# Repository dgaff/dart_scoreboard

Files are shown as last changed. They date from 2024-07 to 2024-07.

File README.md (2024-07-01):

# Electronic Dart Scoreboard for Cricket

## Introduction

Do you like throwing darts? Do you find the pesky chalk or dry erase scoreboards too cumbersome? Well, here's the solution.

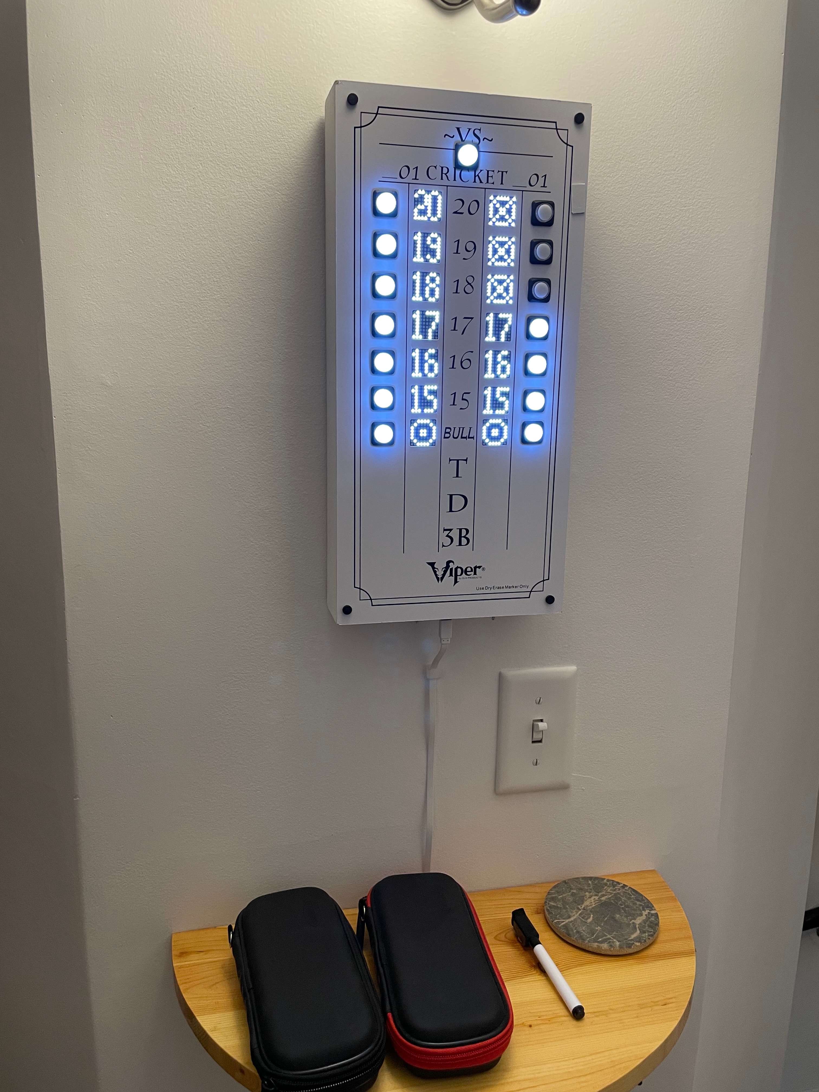
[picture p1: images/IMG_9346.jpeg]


So many lights! So many buttons!

I don't remember what possessed me to take up this project. I think I saw those 8x8 LED matrix displays on AdaFruit and wondered to myself, "Hmmm...I wonder what I could make with those?!" Anyway, this project had a ton of wiring, and because it was so tedious, I think I started and stopped it multiple times over the course of a year. It clearly needed to be a properly designed circuit board rather than a big jumble of wiring harnesses. Had I not started with the dry erase scoreboard as the base template, perhaps my brain would have led me in an easier direction. Nevertheless, it turned out really cool.

So how's it work? Just press the lighted button next to each number and the display will go through single (one slash), double (two slashes), and triple (circle) scoring. When you clear a particular number, that number's button LED will turn off. When one player clears all of the numbers, the reset button does a little animation. And there's a fun startup sequence when you power up or reset the game. I mean, if I'm going to use so many fancy chips, I might as well do something fun, right? Here's a video.

https://github.com/dgaff/dart_scoreboard/assets/1971008/4cacc433-6791-4b03-ad2a-5dbcd5b7c47d

## Parts List

This project was built with a lot of overkill components, and the total price tag was over $400 in parts. At mass production pricing, this might get under $100 in BOM cost, but it would still be pricey.

* [Dart dry erase scoreboard](https://www.amazon.com/gp/product/B004959HHO) - $15
* 14 [LED 8x8 matrix displays](https://www.adafruit.com/product/1079) - $105
* 15 [LED-lit momentary SPST pushbutton switches](https://www.adafruit.com/product/1479) - $30
* 2 [Adafruit Itsy-Bitsy M4](https://www.adafruit.com/product/3800) boards - $30
* 14 [Adafruit MAX 7219 matrix LED controllers](https://www.adafruit.com/product/453) - $182
* 2 [Adafruit TLC 59711 RGB controller](https://www.adafruit.com/product/1455) - $15
* 2 [protoboards](https://www.amazon.com/gp/product/B091PZQ4W7) 7cm x 9cm - $2
* 7 [mini protoboards](https://www.amazon.com/gp/product/B081MSKJJX) (cut in half to make 14) - $10
* 1 SPST toggle switch
* 1 DPDT toggle switch
* 1 [micro USB panel mount jack](https://www.amazon.com/gp/product/B082HZKVP1) - $13
* 1/4" 2' x 4' MDF sheet - $15
* Misc fasteners
* Lots of connector wire, some resistors, and 2 usb-micro pigtails

## Overview

The scoreboard is divided into two halves, with each half controlled by its own separate circuit. Each circuit contains an [Itsy-Bitsy M4](https://www.adafruit.com/product/3800) microprocessor, 7 [8x8 LED boards](https://www.adafruit.com/product/1079), 7 [MAX7219](https://www.adafruit.com/product/453) LED controllers, 7 [lighted push buttons](https://www.adafruit.com/product/1479), and a [TLC59711](https://www.adafruit.com/product/1455) LED controller.

Each scoring number on the scoreboard has its own 8x8 LED display controlled by a MAX7219 and a lighted pushbutton. The 7 LEDs in the push buttons are lit using the TLC59711 controller rather than directly from the microprocessor. This reduces current consumption and allows for dimming effects on the push buttons. I could have added a couple of chips to keep this to a single processor design, but I didn't. As it is, I use most of the IO pins on the Itsy-Bitsy M4.

There's also a reset button in the center that resets the game. This button triggers a reset on both processor boards. However, only the right processor board controls the reset button's LED, which has an animation effect when someone wins. So, the two separate processor boards have TTL serial between them. This is just used by the left processor board to tell the right processor board if the left side won. This will allow the right board to start the reset button animation. The code is written so that the exact same code runs on each board, though.

## Pin Mappings and Partial Schematic

Here are the pin mappings for each of the two Itsy-Bitsy M4 processors. The two processors share power and ground from a single external USB jack on the housing. The only other interconnect between the two processors is the TX and RX lines between them and a shared game reset trigger input on A5.

* SCK, MOSI = SPI bus
* D0, D1, D2, D3, D4, D5, D7 = chip select for MAX controllers (for 8x8 matrices)
* D9, D10, D11, D12, D13, A2, A3 = button inputs
* R0, G0, B0, R1, G1, B1, R2 = game button LED outputs
* G2 = reset button LED output
* A5 = game reset input
* A0, A1 = TX and RX for processor board interconnect

MAX7219 Rset = 20 k&Omega;. I did not change the built-in current limiting resistor on the 59711.

Here's a partial schematic that shows the wiring for one of the 8x8 matrices and its corresponding push button. The 8x8 MAX driver, 8x8 display, and LED pushbutton parts of the circuit are repeated another 6 times. I've labeled the other pins to indicate this. The TX and RX pins are connected to the other processor board (TX->RX and RX->TX of course).

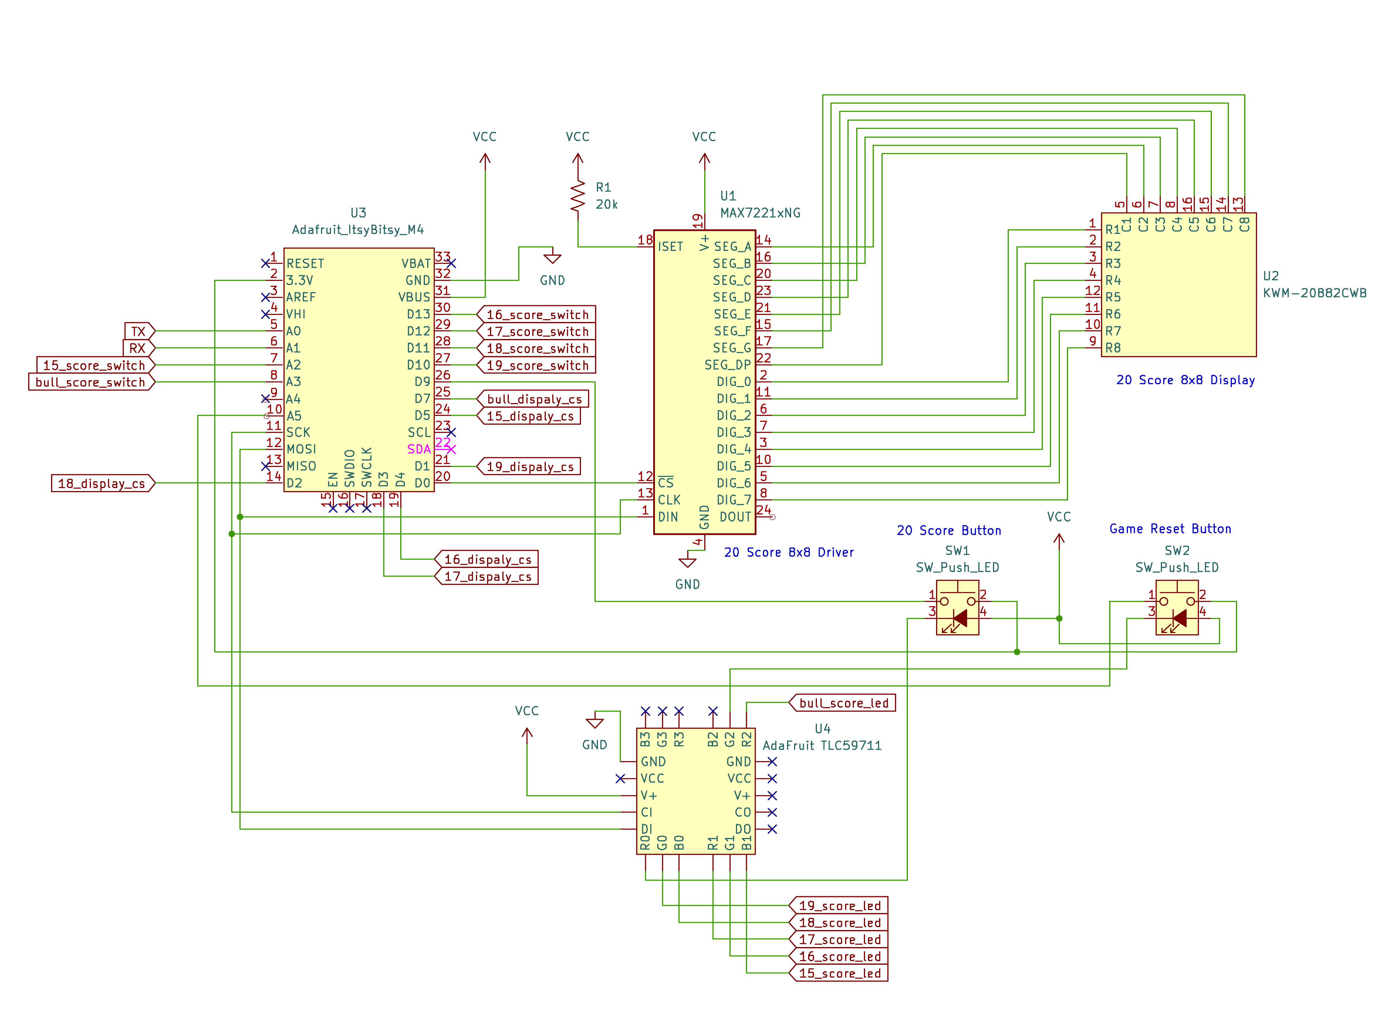
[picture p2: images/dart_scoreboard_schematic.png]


## Prototyping

Before I got too deep into this project, I did some breadboard prototyping to learn how to drive the displays. The MAX7219 controller can be driven by SPI, and each MAX needs a CS line. I had to install the display boards in a certain orientation to get the PCB boards to fit, but the CircuitPython libraries support rotation of the images.

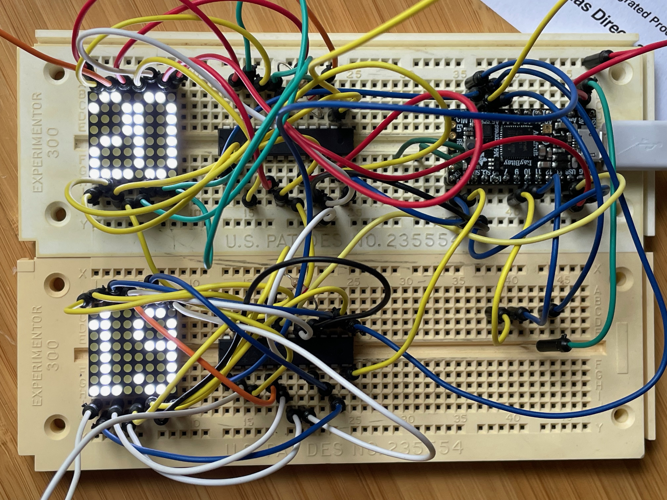
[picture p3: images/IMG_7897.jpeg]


I used the same SPI bus for both the 59711 button LED controller and the MAX7219 8x8 display controllers, as you can see on the schematic above. The 59711 doesn't have a CS like each of the MAX7219's do. But looking at the datasheets and running some tests on the logic analyzer, I decided it wasn't possible to send a bit stream to the MAX7219 controller that would mimic the 59711 bit stream (0x25 write command + 218 bits of data). So I just wired the MOSI and CLK lines to all of the MAX7219 and 59711 controllers.

## Build Steps

### Cutting out the dry erase board

I started with a [dry erase scoreboard](https://www.amazon.com/gp/product/B001E5IC78) from Amazon. I had one of these on the wall next to our dart board already. I found a [square leather punch](https://www.amazon.com/gp/product/B08PB85NFC) to make the square holes in the board for the 8x8 displays. So I made a template in CAD for each display and each push button. Important note: the spacing between each number on this cheap dry erase board is not consistent. This would have made using a single circuit board underneath more challenging. I didn't notice this until I was doing the template in CAD. Second note: at least for me, when I print from CAD (I use Rhino) to a PDF, the scaling is very slightly off when I print the PDF on my LaserJet printer. I'm not sure if this in my printer or if the PDF is off. Regardless, *measure the printout with digital calipers, and adjust the scale factor on the PDF when you print it out.* As the saying goes "measure twice, cut once."

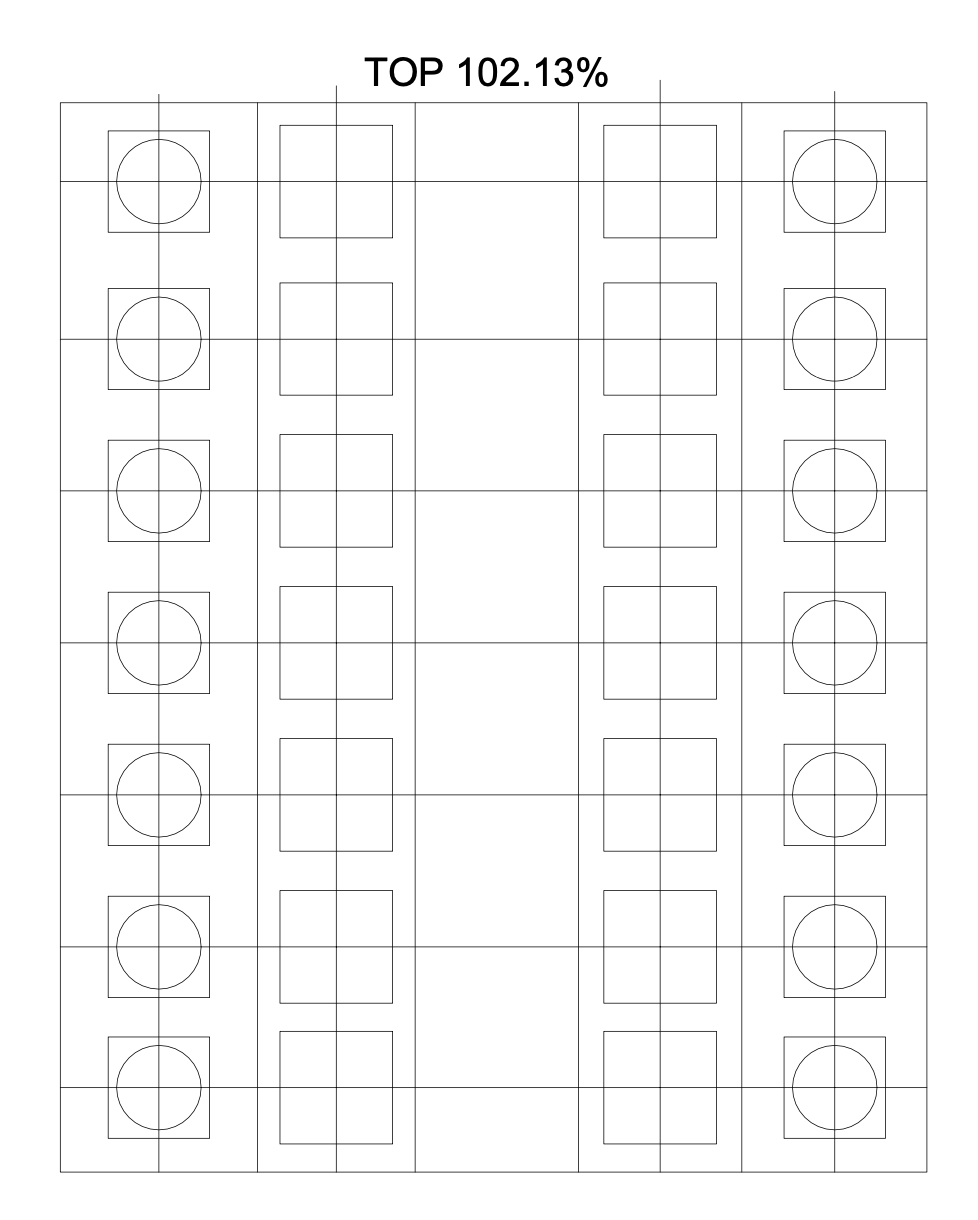
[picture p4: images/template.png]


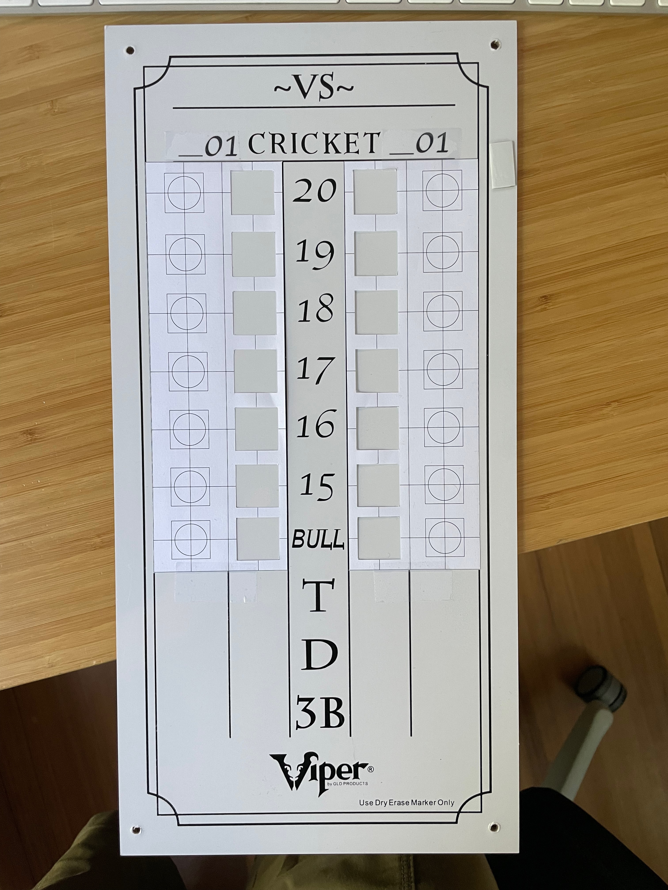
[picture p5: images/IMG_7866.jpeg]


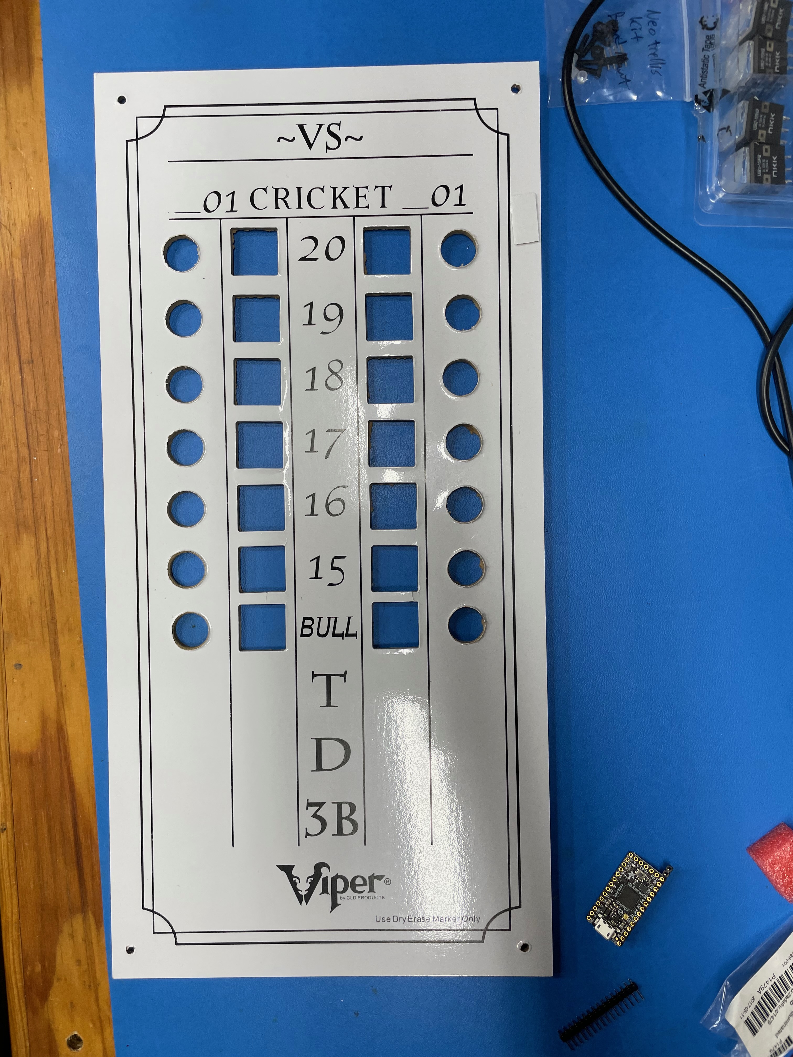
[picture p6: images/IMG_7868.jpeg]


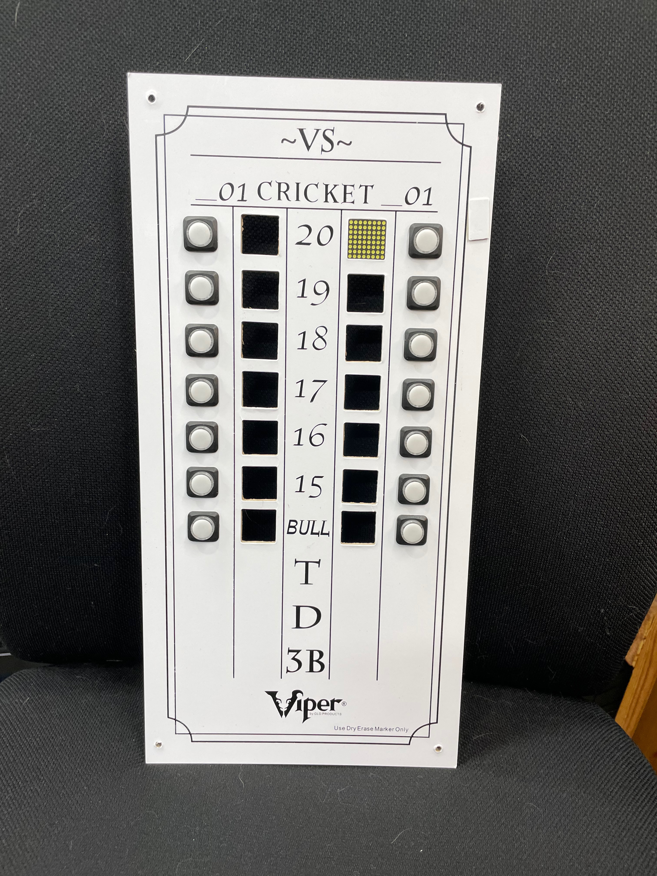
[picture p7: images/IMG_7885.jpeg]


Use the punch carefully! It took some work to cleanly cut each square. The holes for the push buttons were drilled out with a spade bit. I epoxied each display to keep them in place.



### Circuit Boards

Once again, I regret not taking the time to design a circuit board. There are enough components and wiring required that a single, large PCB would have made the job much easier. Certainly a mass-produced board would have one giant PCB for all controllers, displays, and buttons. Also, these DIP packages are large. I assume the SMC versions are quite a bit smaller and would be better suited for a PCB. Note that the MAX7219 requires a current limiting resistor (Rset). I used 20 kΩ. You can see them on the board as well.

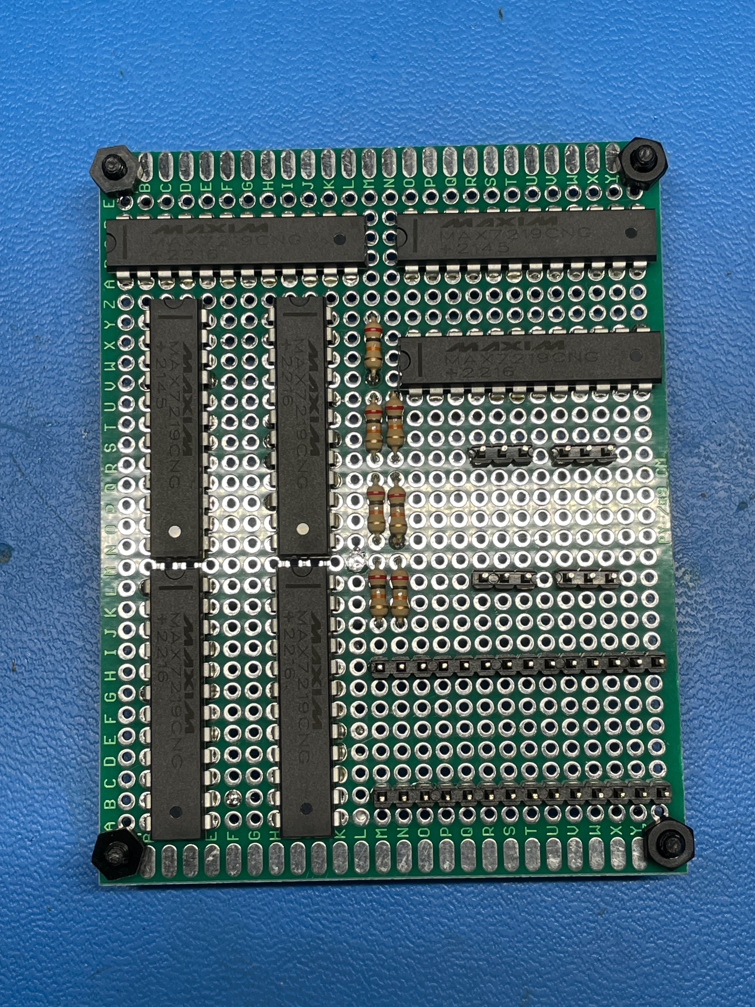
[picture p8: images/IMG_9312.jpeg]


On the top side of the board, I wired: power, ground, chip select, SCK (SPI clock), and MOSI (data).

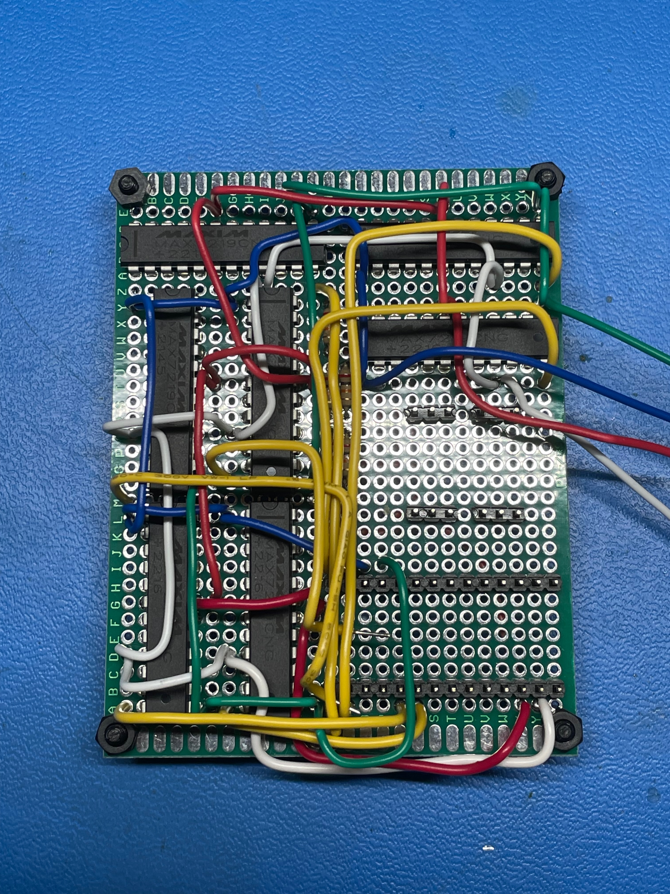
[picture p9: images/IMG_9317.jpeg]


I soldered the M4 in place at a later stage in the process, because it was easier to wire up all of the IO lines without the M4 daughter board in place. I also soldered up the 59711 controller later in the process for the same reason. The push button LED lines are much easier to solder in when the daughter board is out of the way. But this is what is looks like with the daughter boards in place. NOTE: I used solid copper wire for the top board in order to keep everything in place and mostly out of the way for the time when I would wire up the displays.

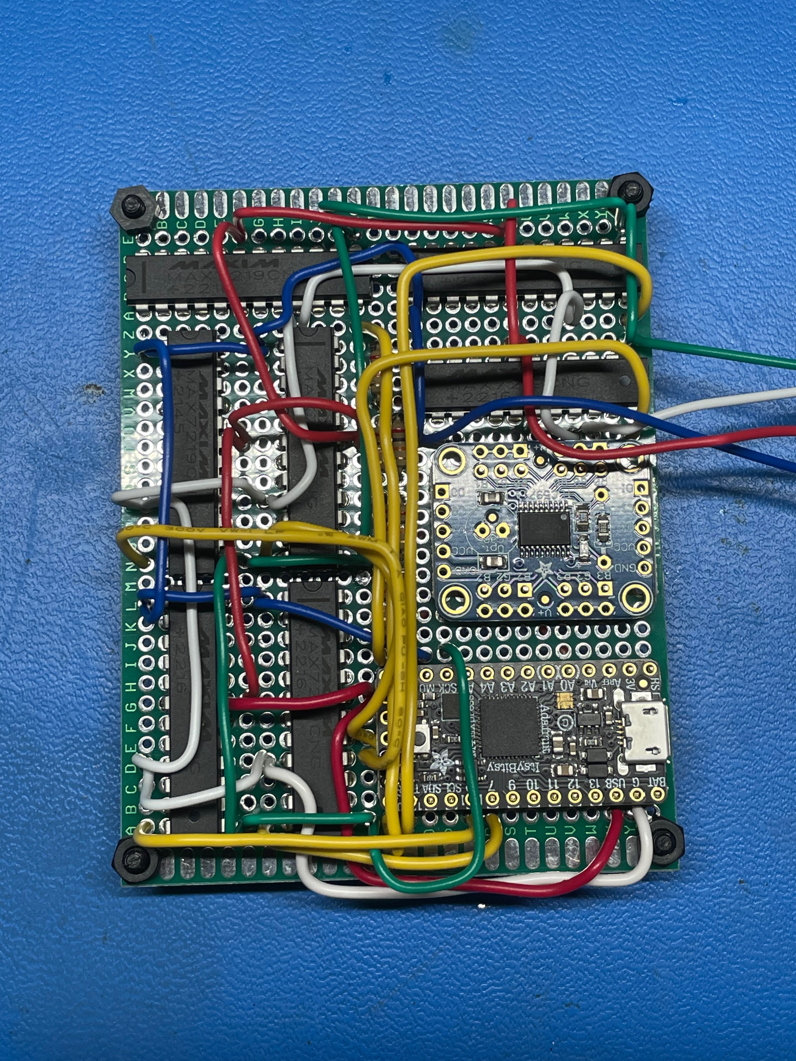
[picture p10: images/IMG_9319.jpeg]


I used the bottom of the board to wire up Rset for each MAX chip. I used stranded copper connecting wiring for this. Looking back, perhaps I could have used a single Rset for all of the MAX chips. I should have tested that out.

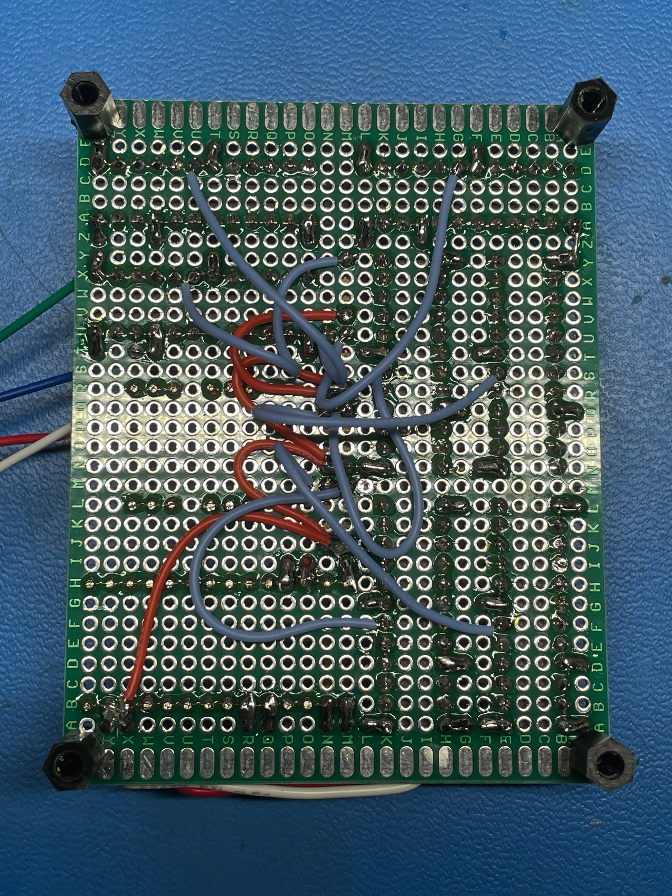
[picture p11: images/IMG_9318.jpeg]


Wiring up each 8x8 display was a real pain in the ass. First, I cut some small circuit boards in half to get them to fit next to each other on the back side of the dry erase scoreboard (given how close the 8x8 matrices were together). I had hoped I could use a single board to straddle multiple displays, but given the inconsistent font space on the dry erase scoreboard, I had to do one board for each display. (Did I mention that I started and stopped this project multiple times over the course of a year?) Then I made wiring harnesses for each display.

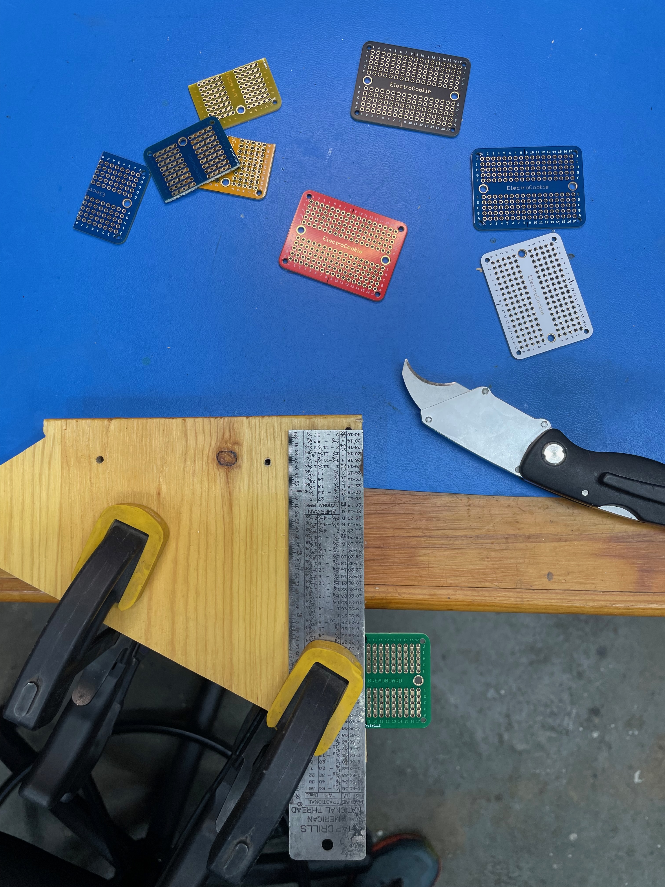
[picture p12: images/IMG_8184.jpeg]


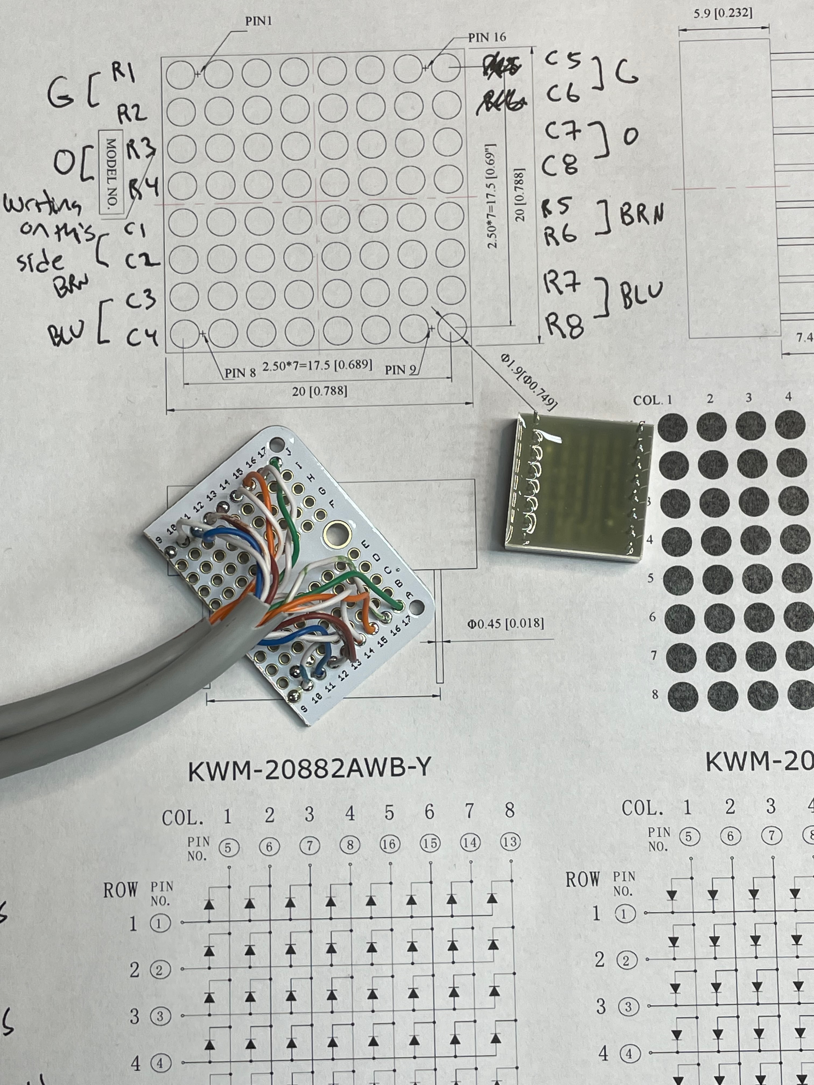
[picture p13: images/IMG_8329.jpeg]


Lastly, I made a bed-of-nails test board to check each wiring harness after it was soldered into it's corresponding MAC controller. Why? Because errors, that's why. I made a lot of wiring mistakes doing this very monotonous wiring task. This tester helped me catch those errors.

Also, there's another important reason. **The 8x8 LED datasheet warns not to use too much heat when soldering the displays and to not resolder them.** They say that you will damage the display if you use too much heat or solder for too long. So, I was worried that there was no room for error on the daughter boards, and given that these displays are epoxied in, I didn't want to have to rip one out.

That said, this bed-of-nails setup didn't work that great. The pogo pins didn't make very good electrical contact with the 8x8 daughter board. It was good enough to generally verify that I had wired up the daughter board correctly, but it wasn't perfect. Perhaps I needed some pogo pins with a sharper point. I'm not sure.



### Even more soldering...

As you can see from the picture, there was a ton of wiring and soldering to connect the display daughter board to the MAX controller chips.



And then there was soldering the 8x8 matrix daughter boards to the displays, which was stressful as I mentioned above because of the reduced temperature and limited solder time duration that the datasheet warned about.

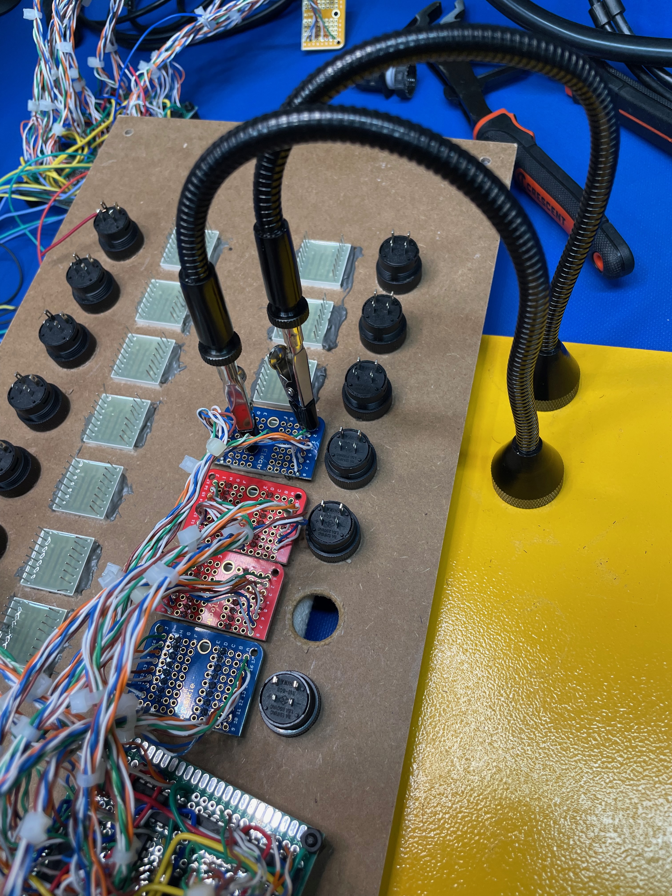
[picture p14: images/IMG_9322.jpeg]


Look at this monstrosity when everything is wired up on one side! It looks like the inside of an old school pinball machine.

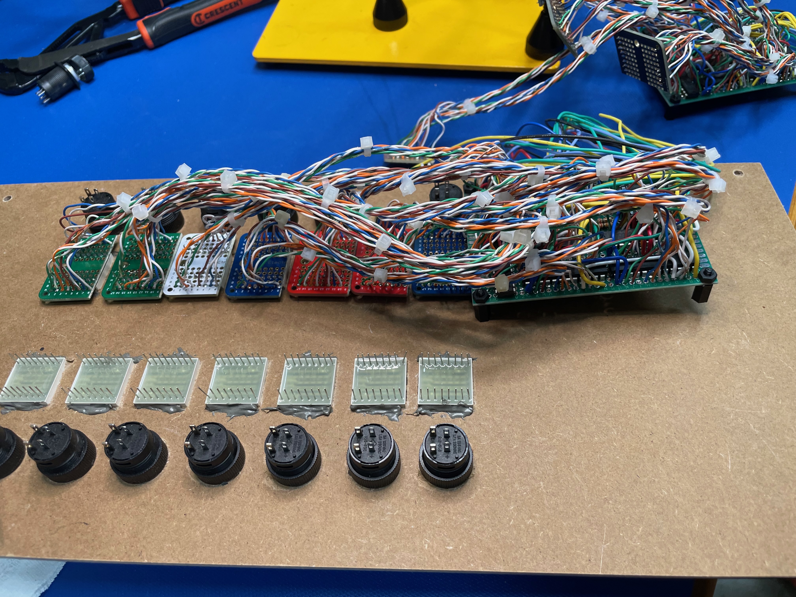
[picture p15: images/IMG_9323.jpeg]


As noted, to mass produce this, I would build one large circuit board that held the displays, push buttons, and remaining circuitry. I would also use discrete LEDs for the 8x8 matrix instead of the Luckylight modules from Adafruit. They are quite pricey. The MAX controller chips are expensive too, but I suspect the price drops quite a bit in large quantities.

### Building the housing

I bought some 1/4 inch thick MDF to build the housing for the scoreboard. Here's the frame of the box getting glued together. 1/4 MDF is a little small for nails.

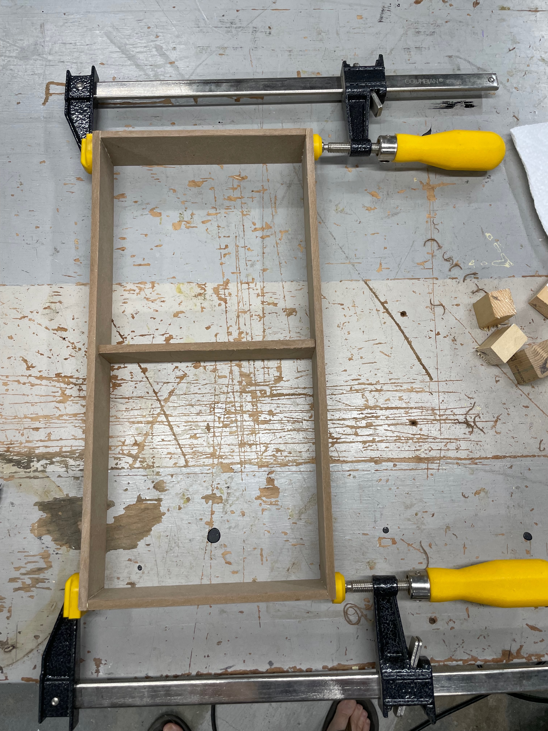
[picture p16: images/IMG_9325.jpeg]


And here's the frame getting glued to the score board.

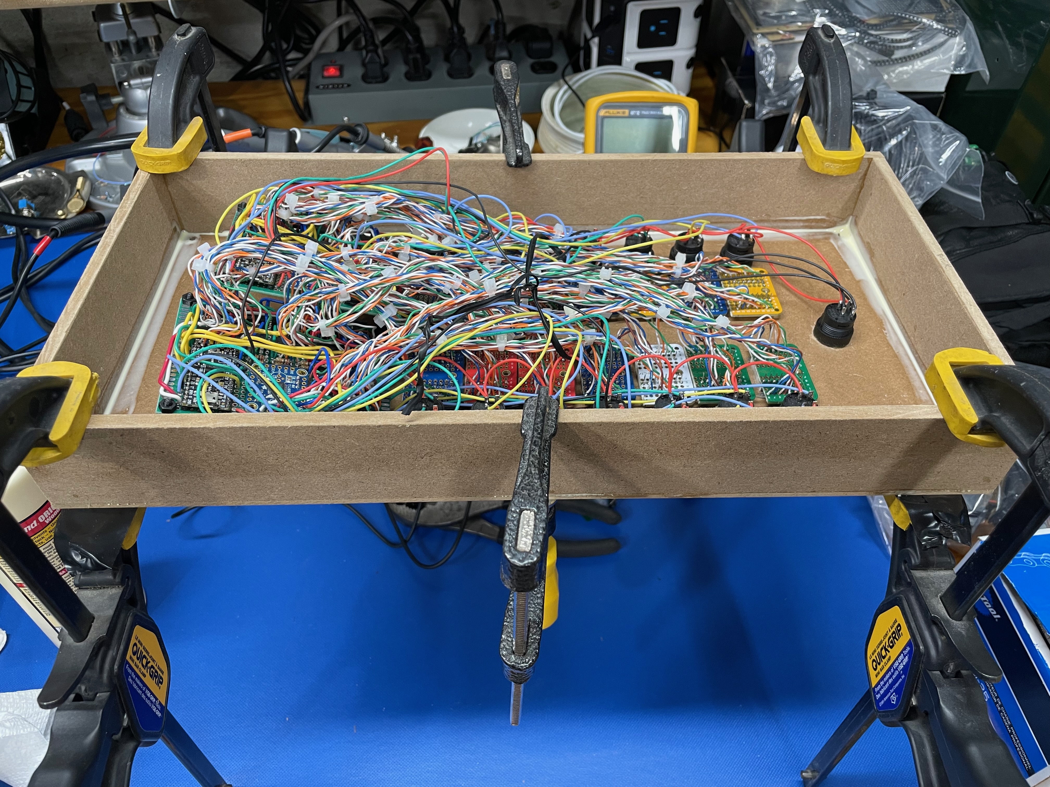
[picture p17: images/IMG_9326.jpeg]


Here's what it looked like before I added some structural components.

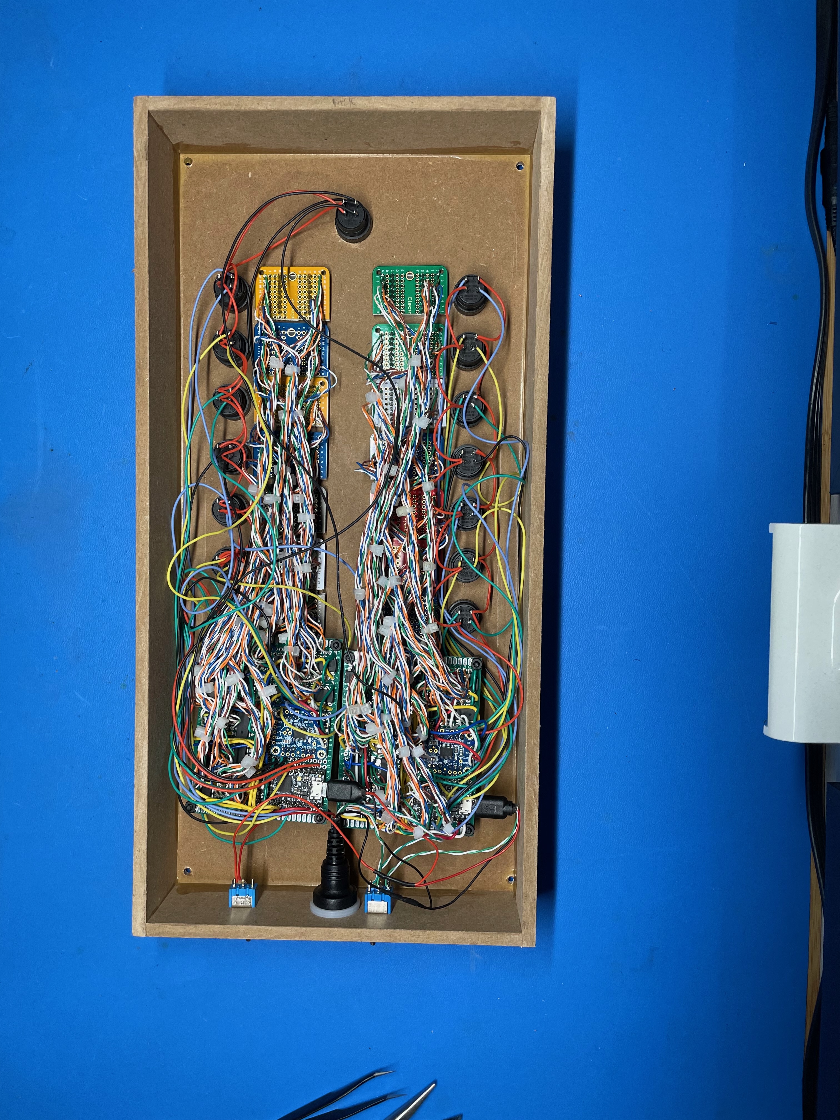
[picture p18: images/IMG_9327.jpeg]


You can see on the bottom that there are two switches and a USB jack. 

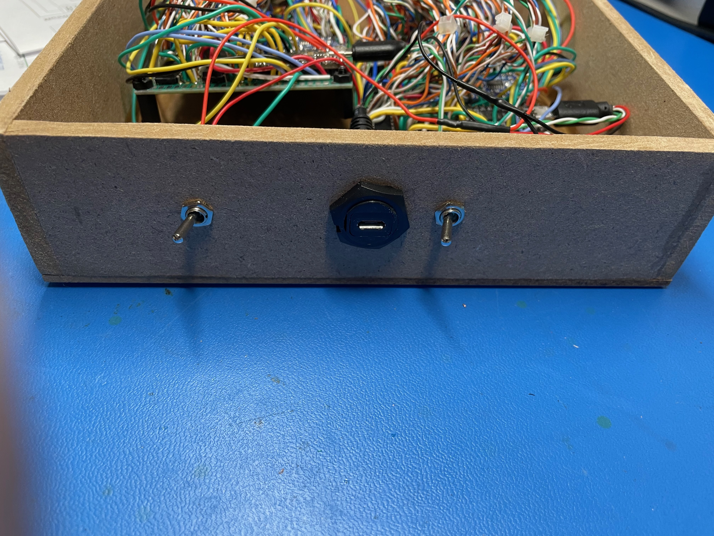
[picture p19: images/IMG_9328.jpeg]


The left switch in the picture is the power switch. Power from the single USB jack is shared between the two processor board. The right switch toggles the USB TX/RX lines between the left and right boards. This is used for programming. So when the USB is connected in the laptop, the Circuit Python drive for the selected board will shop up in Finder. This is incredibly convenient for testing out new code. You can see the wiring here.

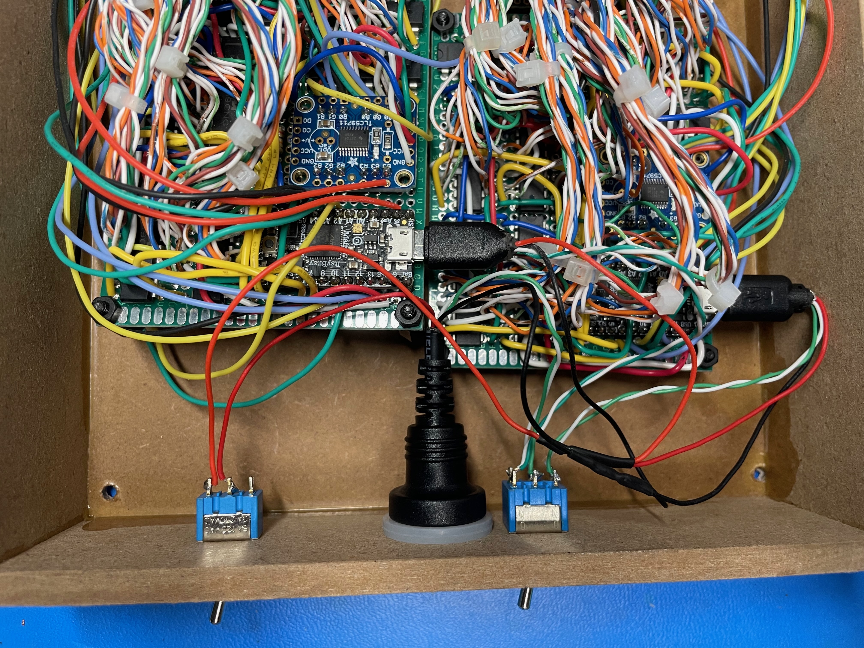
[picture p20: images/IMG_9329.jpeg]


The only downside if that if I ever have to update the core Itsy-Bitsy firmware, I'll have to open the box up, since you must double-click the reset button in order to see the boot loader partition on your laptop. Perhaps there's a way to do this programmatically. I'll have to look into it.

### Attaching to the wall

In order to increase the structural integrity of the box, I decided to glue in some additional support blocks that will hold the keyhole mounts. 1/4" MDF is pretty thin, and I didn't want to rely on it alone to hold the scoreboard to the wall. I also put a center piece of wood to provide some structural support for the front of the scoreboard, since users will be pressing buttons on the front of the board, and the dry erase front scoreboard is only about 1/8" thick.

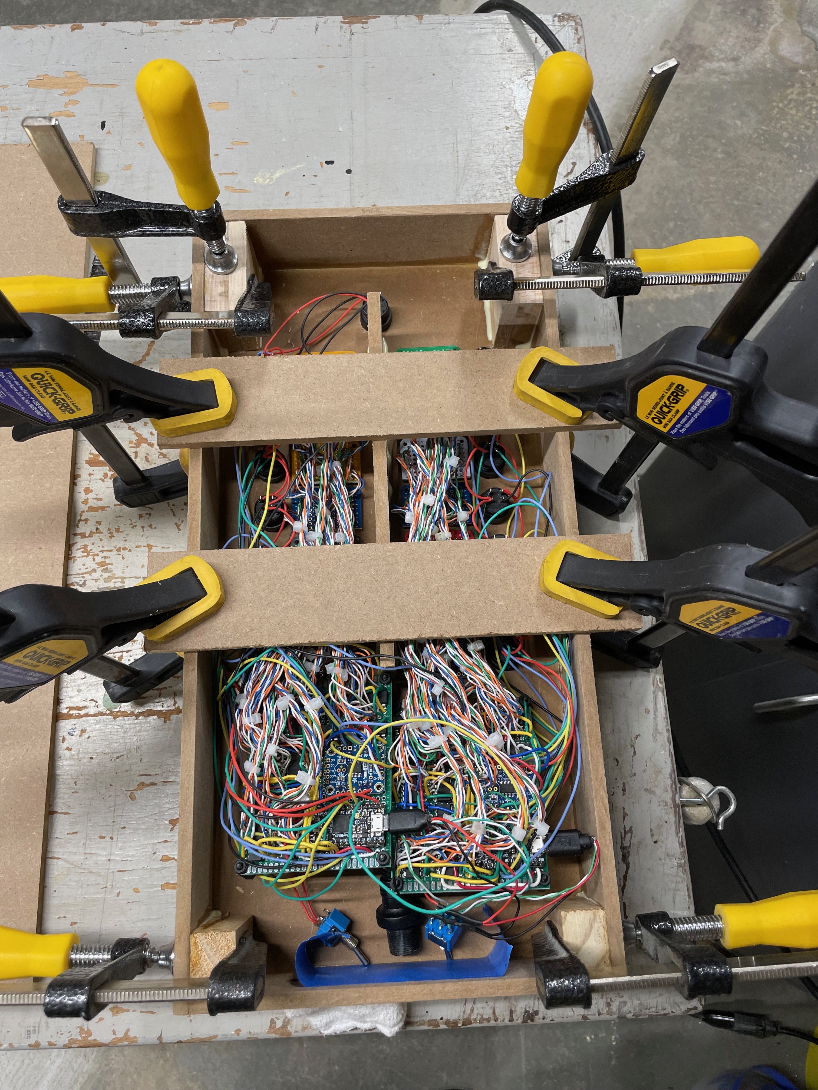
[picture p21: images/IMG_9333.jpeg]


Here's the guts after the glue dried and the screw holes are in place. The sides and back are painted, and the keyhole connectors attached. I painted the box with Rustoleum flat white enamel.

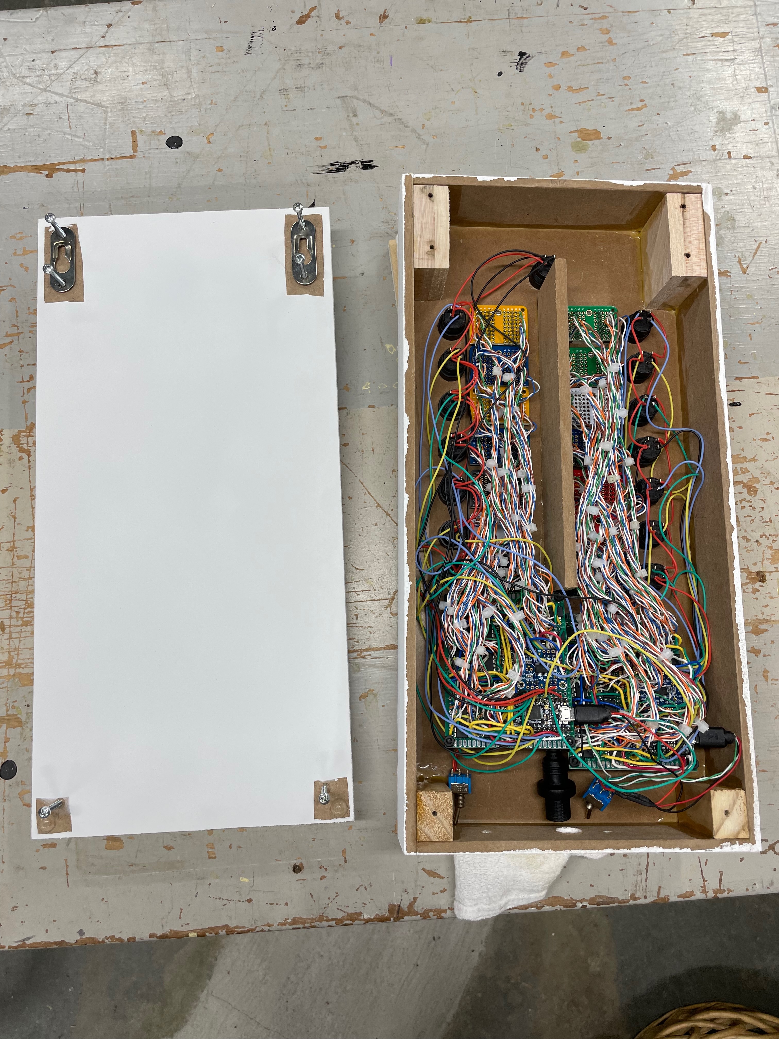
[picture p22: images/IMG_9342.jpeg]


## Misc

* My wife wants the scoreboard to play a little tune when someone wins. :) Guess I'll need to add that to a future version.
* Data sheets and circuit python info are all on the parts links above.
* While searching for ways to do the numbers, I came across the [C-64 character set](https://fabienroyer.wordpress.com/2010/12/03/driving-an-8x8-led-matrix-with-a-netduino-using-persistence-of-vision/). The code is gone, but you can still download the characters. I thought it might be cool to have the Commodore 64 character set on the board, although I didn't end up using it. Perhaps for another project. Here's the character set in case you want to 





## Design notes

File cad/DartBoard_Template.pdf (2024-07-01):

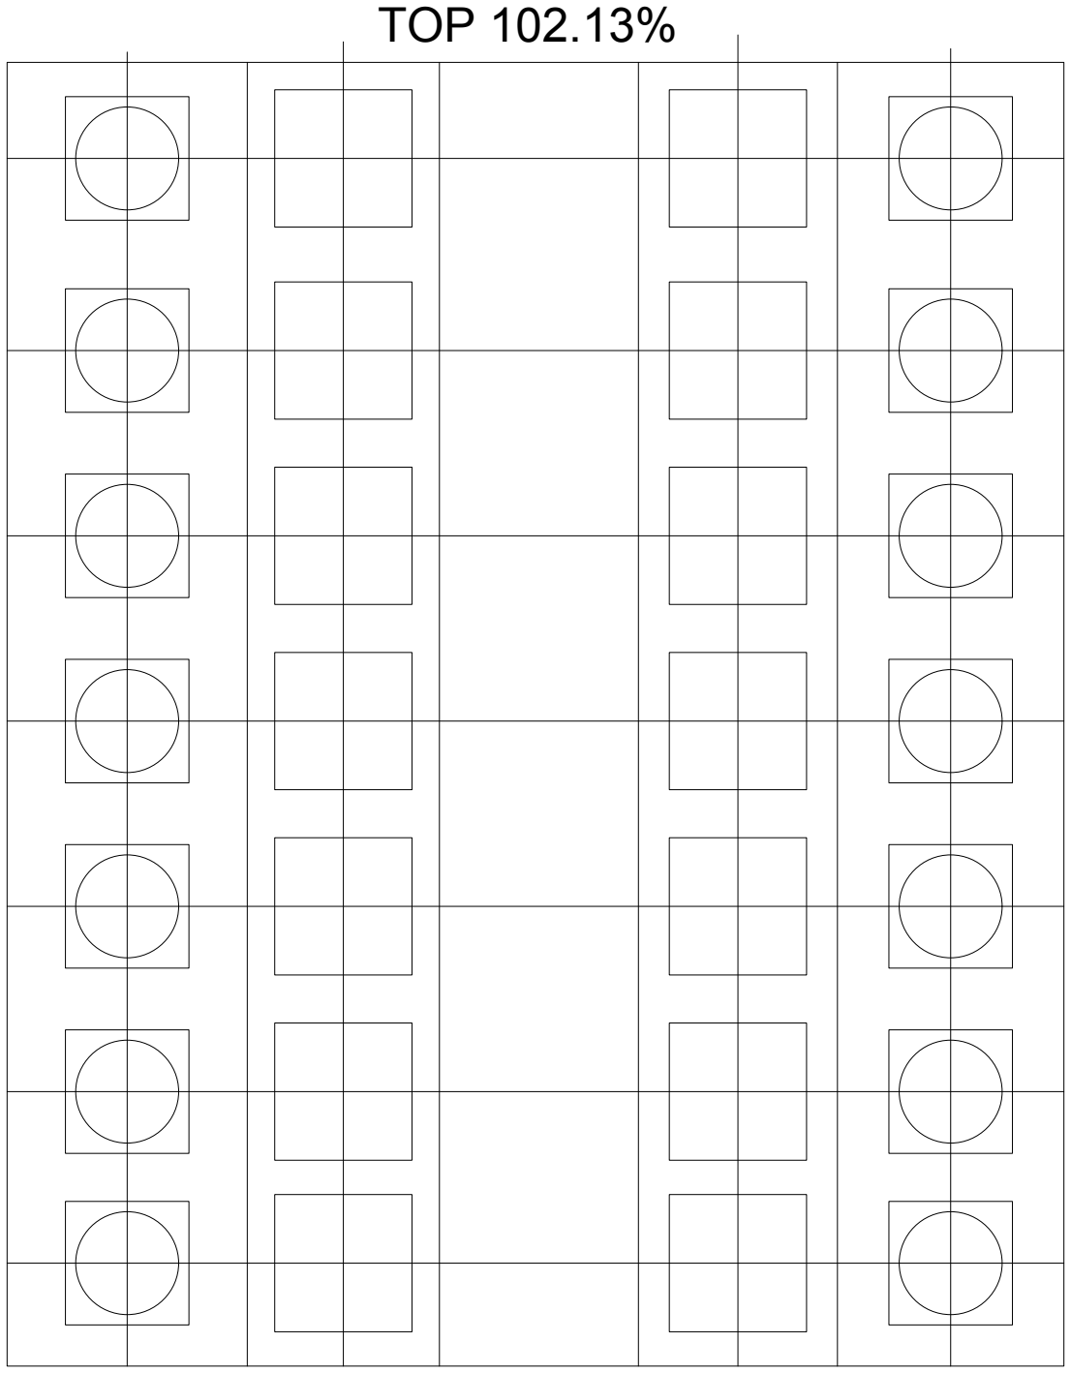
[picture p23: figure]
TOP 102.13%

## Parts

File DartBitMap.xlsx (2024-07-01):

 | 0 | 1 | 2 | 3 | 4 | 5 | 6 | 7
0 |  | X | X |  |  | X | X |  | [[0, 1, 1, 0, 0, 1, 1, 0],
1 | X |  |  | X | X |  |  | X | [1, 0, 0, 1, 1, 0, 0, 1],
2 |  |  |  | X | X |  |  | X | [0, 0, 0, 1, 1, 0, 0, 1],
3 |  |  |  | X | X |  |  | X | [0, 0, 0, 1, 1, 0, 0, 1],
4 |  | X | X |  | X |  |  | X | [0, 1, 1, 0, 1, 0, 0, 1],
5 | X |  |  |  | X |  |  | X | [1, 0, 0, 0, 1, 0, 0, 1],
6 | X |  |  |  | X |  |  | X | [1, 0, 0, 0, 1, 0, 0, 1],
7 | X | X | X | X |  | X | X |  | [1, 1, 1, 1, 0, 1, 1, 0]]
0 |  | X |  |  |  | X | X |  | [[0, 1, 0, 0, 0, 1, 1, 0],
1 | X | X |  |  | X |  |  | X | [1, 1, 0, 0, 1, 0, 0, 1],
2 |  | X |  |  | X |  |  | X | [0, 1, 0, 0, 1, 0, 0, 1],
3 |  | X |  |  |  | X | X | X | [0, 1, 0, 0, 0, 1, 1, 1],
4 |  | X |  |  |  |  |  | X | [0, 1, 0, 0, 0, 0, 0, 1],
5 |  | X |  |  |  |  |  | X | [0, 1, 0, 0, 0, 0, 0, 1],
6 |  | X |  |  | X |  |  | X | [0, 1, 0, 0, 1, 0, 0, 1],
7 | X | X | X |  |  | X | X |  | [1, 1, 1, 0, 0, 1, 1, 0]]
0 |  | X |  |  |  | X | X |  | [[0, 1, 0, 0, 0, 1, 1, 0],
1 | X | X |  |  | X |  |  | X | [1, 1, 0, 0, 1, 0, 0, 1],
2 |  | X |  |  | X |  |  | X | [0, 1, 0, 0, 1, 0, 0, 1],
3 |  | X |  |  |  | X | X |  | [0, 1, 0, 0, 0, 1, 1, 0],
4 |  | X |  |  | X |  |  | X | [0, 1, 0, 0, 1, 0, 0, 1],
5 |  | X |  |  | X |  |  | X | [0, 1, 0, 0, 1, 0, 0, 1],
6 |  | X |  |  | X |  |  | X | [0, 1, 0, 0, 1, 0, 0, 1],
7 | X | X | X |  |  | X | X |  | [1, 1, 1, 0, 0, 1, 1, 0]]
0 |  | X |  |  | X | X | X | X | [[0, 1, 0, 0, 1, 1, 1, 1],
1 | X | X |  |  |  |  |  | X | [1, 1, 0, 0, 0, 0, 0, 1],
2 |  | X |  |  |  |  |  | X | [0, 1, 0, 0, 0, 0, 0, 1],
3 |  | X |  |  |  |  | X |  | [0, 1, 0, 0, 0, 0, 1, 0],
4 |  | X |  |  |  |  | X |  | [0, 1, 0, 0, 0, 0, 1, 0],
5 |  | X |  |  |  | X |  |  | [0, 1, 0, 0, 0, 1, 0, 0],
6 |  | X |  |  |  | X |  |  | [0, 1, 0, 0, 0, 1, 0, 0],
7 | X | X | X |  |  | X |  |  | [1, 1, 1, 0, 0, 1, 0, 0]]
0 |  | X |  |  |  | X | X |  | [[0, 1, 0, 0, 0, 1, 1, 0],
1 | X | X |  |  | X |  |  |  | [1, 1, 0, 0, 1, 0, 0, 0],
2 |  | X |  |  | X |  |  |  | [0, 1, 0, 0, 1, 0, 0, 0],
3 |  | X |  |  |  | X | X |  | [0, 1, 0, 0, 0, 1, 1, 0],
4 |  | X |  |  | X |  |  | X | [0, 1, 0, 0, 1, 0, 0, 1],
5 |  | X |  |  | X |  |  | X | [0, 1, 0, 0, 1, 0, 0, 1],
6 |  | X |  |  | X |  |  | X | [0, 1, 0, 0, 1, 0, 0, 1],
7 | X | X | X |  |  | X | X |  | [1, 1, 1, 0, 0, 1, 1, 0]]
0 |  | X |  |  | X | X | X | X | [[0, 1, 0, 0, 1, 1, 1, 1],
1 | X | X |  |  | X |  |  |  | [1, 1, 0, 0, 1, 0, 0, 0],
2 |  | X |  |  | X |  |  |  | [0, 1, 0, 0, 1, 0, 0, 0],
3 |  | X |  |  |  | X | X |  | [0, 1, 0, 0, 0, 1, 1, 0],
4 |  | X |  |  |  |  |  | X | [0, 1, 0, 0, 0, 0, 0, 1],
5 |  | X |  |  |  |  |  | X | [0, 1, 0, 0, 0, 0, 0, 1],
6 |  | X |  |  |  |  |  | X | [0, 1, 0, 0, 0, 0, 0, 1],
7 | X | X | X |  | X | X | X |  | [1, 1, 1, 0, 1, 1, 1, 0]]
0 | X |  | X | X | X | X |  | X | [[1, 0, 1, 1, 1, 1, 0, 1],
1 |  | X |  |  |  |  | X |  | [0, 1, 0, 0, 0, 0, 1, 0],
2 | X |  | X |  |  | X |  | X | [1, 0, 1, 0, 0, 1, 0, 1],
3 | X |  |  | X | X |  |  | X | [1, 0, 0, 1, 1, 0, 0, 1],
4 | X |  |  | X | X |  |  | X | [1, 0, 0, 1, 1, 0, 0, 1],
5 | X |  | X |  |  | X |  | X | [1, 0, 1, 0, 0, 1, 0, 1],
6 |  | X |  |  |  |  | X |  | [0, 1, 0, 0, 0, 0, 1, 0],
7 | X |  | X | X | X | X |  | X | [1, 0, 1, 1, 1, 1, 0, 1]]
0 |  |  | X | X | X | X |  |  | [[0, 0, 1, 1, 1, 1, 0, 0],
1 |  | X |  |  |  |  | X |  | [0, 1, 0, 0, 0, 0, 1, 0],
2 | X |  | X |  |  | X |  | X | [1, 0, 1, 0, 0, 1, 0, 1],
3 | X |  |  | X | X |  |  | X | [1, 0, 0, 1, 1, 0, 0, 1],
4 | X |  |  | X | X |  |  | X | [1, 0, 0, 1, 1, 0, 0, 1],
5 | X |  | X |  |  | X |  | X | [1, 0, 1, 0, 0, 1, 0, 1],
6 |  | X |  |  |  |  | X |  | [0, 1, 0, 0, 0, 0, 1, 0],
7 |  |  | X | X | X | X |  |  | [0, 0, 1, 1, 1, 1, 0, 0]]
0 |  |  | X | X | X | X |  |  | [[0, 0, 1, 1, 1, 1, 0, 0],
1 |  | X |  |  |  |  | X |  | [0, 1, 0, 0, 0, 0, 1, 0],
2 | X |  |  |  |  |  |  | X | [1, 0, 0, 0, 0, 0, 0, 1],
3 | X |  |  | X | X |  |  | X | [1, 0, 0, 1, 1, 0, 0, 1],
4 | X |  |  | X | X |  |  | X | [1, 0, 0, 1, 1, 0, 0, 1],
5 | X |  |  |  |  |  |  | X | [1, 0, 0, 0, 0, 0, 0, 1],
6 |  | X |  |  |  |  | X |  | [0, 1, 0, 0, 0, 0, 1, 0],
7 |  |  | X | X | X | X |  |  | [0, 0, 1, 1, 1, 1, 0, 0]]
0 | X |  |  |  |  |  |  |  | [[1, 0, 0, 0, 0, 0, 0, 0],
1 |  | X |  |  |  |  |  |  | [0, 1, 0, 0, 0, 0, 0, 0],
2 |  |  | X |  |  |  |  |  | [0, 0, 1, 0, 0, 0, 0, 0],
3 |  |  |  | X |  |  |  |  | [0, 0, 0, 1, 0, 0, 0, 0],
4 |  |  |  |  | X |  |  |  | [0, 0, 0, 0, 1, 0, 0, 0],
5 |  |  |  |  |  | X |  |  | [0, 0, 0, 0, 0, 1, 0, 0],
6 |  |  |  |  |  |  | X |  | [0, 0, 0, 0, 0, 0, 1, 0],
7 |  |  |  |  |  |  |  | X | [0, 0, 0, 0, 0, 0, 0, 1]]
0 | X |  |  |  |  |  |  | X | [[1, 0, 0, 0, 0, 0, 0, 1],
1 |  | X |  |  |  |  | X |  | [0, 1, 0, 0, 0, 0, 1, 0],
2 |  |  | X |  |  | X |  |  | [0, 0, 1, 0, 0, 1, 0, 0],
3 |  |  |  | X | X |  |  |  | [0, 0, 0, 1, 1, 0, 0, 0],
4 |  |  |  | X | X |  |  |  | [0, 0, 0, 1, 1, 0, 0, 0],
5 |  |  | X |  |  | X |  |  | [0, 0, 1, 0, 0, 1, 0, 0],
6 |  | X |  |  |  |  | X |  | [0, 1, 0, 0, 0, 0, 1, 0],
7 | X |  |  |  |  |  |  | X | [1, 0, 0, 0, 0, 0, 0, 1]]

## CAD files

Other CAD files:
cad/DartBoard_Template.3dm

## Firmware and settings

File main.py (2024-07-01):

# (c) 2024 Douglas Gaff
# All Rights Reserved

import time
import board
import digitalio
from adafruit_max7219 import matrices
from adafruit_debouncer import Debouncer
import adafruit_tlc59711

# Setup the SPI bus.
spi = board.SPI() # defaults to SCK and MOSI pins

# Setup the display controller chip selects
display_cs = [
    digitalio.DigitalInOut(board.D0),
    digitalio.DigitalInOut(board.D1),
    digitalio.DigitalInOut(board.D2),
    digitalio.DigitalInOut(board.D3),
    digitalio.DigitalInOut(board.D4),
    digitalio.DigitalInOut(board.D5),
    digitalio.DigitalInOut(board.D7)
]

# Setup the button LED controller chip select
score_button_LED_cs = digitalio.DigitalInOut(board.A4)

# Button inputs
score_button_pins = [
    digitalio.DigitalInOut(board.D9),
    digitalio.DigitalInOut(board.D10),
    digitalio.DigitalInOut(board.D11),
    digitalio.DigitalInOut(board.D12),
    digitalio.DigitalInOut(board.D13),
    digitalio.DigitalInOut(board.A2),
    digitalio.DigitalInOut(board.A3)
]

for pin in score_button_pins:
    pin.direction = digitalio.Direction.INPUT
    pin.pull = digitalio.Pull.DOWN

score_buttons = []
for pin in score_button_pins:
    score_buttons.append(Debouncer(pin, interval = 0.05))

# TX and RX so the two boards can talk to each other. Just used as high and low right now
# for indicating the end of the game.
serial_pins = [
    digitalio.DigitalInOut(board.A0),
    digitalio.DigitalInOut(board.A1)
]

TX = 0
RX = 1
serial_pins[TX].direction = digitalio.Direction.OUTPUT
serial_pins[RX].direction = digitalio.Direction.INPUT
serial_pins[RX].pull = digitalio.Pull.DOWN

# Score button LEDS
leds = adafruit_tlc59711.TLC59711(spi)

score_button_led_channel = [
    9,   # R0 silkscreen
    10,  # G0 silkscreen
    11,  # B0 silkscreen
    6,   # R1 silkscreen
    7,   # G1 silkscreen
    8,   # B1 silkscreen
    3,   # R2 silkscreen
    4,   # G2 silkscreen
    5,   # B2 silkscreen
    0,   # R3 silkscreen
    1,   # G3 silkscreen
    2    # B3 silkscreen
]

# Game reset button
reset_button_pin = digitalio.DigitalInOut(board.A5)
reset_button_pin.direction = digitalio.Direction.INPUT
reset_button_pin.pull = digitalio.Pull.DOWN
reset_button = Debouncer(reset_button_pin, interval = 0.05)

# Setup the displays
# TODO Figure out the correct rotation after I hook things up.
# Note: for some reason I can't pass rotation to the Matrix8x8 constructor. So I'm using CustomMatrix.
# matrices.Matrix8x8(spi, display_cs[0])

display_matrix = [
    # matrices.Matrix8x8(spi, display_cs[0]),  # this is how you declare if you don't need rotation.
    # matrices.Matrix8x8(spi, display_cs[1]),
    # matrices.Matrix8x8(spi, display_cs[2]),
    # matrices.Matrix8x8(spi, display_cs[3]),
    # matrices.Matrix8x8(spi, display_cs[4]),
    # matrices.Matrix8x8(spi, display_cs[5]),
    # matrices.Matrix8x8(spi, display_cs[6])
    matrices.CustomMatrix(spi, display_cs[0],8,8,rotation=3),
    matrices.CustomMatrix(spi, display_cs[1],8,8,rotation=3),
    matrices.CustomMatrix(spi, display_cs[2],8,8,rotation=3),
    matrices.CustomMatrix(spi, display_cs[3],8,8,rotation=3),
    matrices.CustomMatrix(spi, display_cs[4],8,8,rotation=3),
    matrices.CustomMatrix(spi, display_cs[5],8,8,rotation=3),
    matrices.CustomMatrix(spi, display_cs[6],8,8,rotation=3)
]

# Set the display brightness
# TODO I think the max brightness is current limited. Need to measure before I set the default.
for matrix in display_matrix:
    matrix.brightness(10)

# Bitmaps for 8x8 displays

twenty = [[0, 1, 1, 0, 0, 1, 1, 0],
 [1, 0, 0, 1, 1, 0, 0, 1],
 [0, 0, 0, 1, 1, 0, 0, 1],
 [0, 0, 0, 1, 1, 0, 0, 1],
 [0, 1, 1, 0, 1, 0, 0, 1],
 [1, 0, 0, 0, 1, 0, 0, 1],
 [1, 0, 0, 0, 1, 0, 0, 1],
 [1, 1, 1, 1, 0, 1, 1, 0]]

nineteen = [[0, 1, 0, 0, 0, 1, 1, 0],
 [1, 1, 0, 0, 1, 0, 0, 1],
 [0, 1, 0, 0, 1, 0, 0, 1],
 [0, 1, 0, 0, 0, 1, 1, 1],
 [0, 1, 0, 0, 0, 0, 0, 1],
 [0, 1, 0, 0, 0, 0, 0, 1],
 [0, 1, 0, 0, 1, 0, 0, 1],
 [1, 1, 1, 0, 0, 1, 1, 0]]

eighteen = [[0, 1, 0, 0, 0, 1, 1, 0],
 [1, 1, 0, 0, 1, 0, 0, 1],
 [0, 1, 0, 0, 1, 0, 0, 1],
 [0, 1, 0, 0, 0, 1, 1, 0],
 [0, 1, 0, 0, 1, 0, 0, 1],
 [0, 1, 0, 0, 1, 0, 0, 1],
 [0, 1, 0, 0, 1, 0, 0, 1],
 [1, 1, 1, 0, 0, 1, 1, 0]]

seventeen = [[0, 1, 0, 0, 1, 1, 1, 1],
 [1, 1, 0, 0, 0, 0, 0, 1],
 [0, 1, 0, 0, 0, 0, 0, 1],
 [0, 1, 0, 0, 0, 0, 1, 0],
 [0, 1, 0, 0, 0, 0, 1, 0],
 [0, 1, 0, 0, 0, 1, 0, 0],
 [0, 1, 0, 0, 0, 1, 0, 0],
 [1, 1, 1, 0, 0, 1, 0, 0]]

sixteen = [[0, 1, 0, 0, 0, 1, 1, 0],
 [1, 1, 0, 0, 1, 0, 0, 0],
 [0, 1, 0, 0, 1, 0, 0, 0],
 [0, 1, 0, 0, 0, 1, 1, 0],
 [0, 1, 0, 0, 1, 0, 0, 1],
 [0, 1, 0, 0, 1, 0, 0, 1],
 [0, 1, 0, 0, 1, 0, 0, 1],
 [1, 1, 1, 0, 0, 1, 1, 0]]

fifteen = [[0, 1, 0, 0, 1, 1, 1, 1],
 [1, 1, 0, 0, 1, 0, 0, 0],
 [0, 1, 0, 0, 1, 0, 0, 0],
 [0, 1, 0, 0, 0, 1, 1, 0],
 [0, 1, 0, 0, 0, 0, 0, 1],
 [0, 1, 0, 0, 0, 0, 0, 1],
 [0, 1, 0, 0, 0, 0, 0, 1],
 [1, 1, 1, 0, 1, 1, 1, 0]]

bull = [[0, 0, 1, 1, 1, 1, 0, 0],
 [0, 1, 0, 0, 0, 0, 1, 0],
 [1, 0, 0, 0, 0, 0, 0, 1],
 [1, 0, 0, 1, 1, 0, 0, 1],
 [1, 0, 0, 1, 1, 0, 0, 1],
 [1, 0, 0, 0, 0, 0, 0, 1],
 [0, 1, 0, 0, 0, 0, 1, 0],
 [0, 0, 1, 1, 1, 1, 0, 0]]

single = [[1, 0, 0, 0, 0, 0, 0, 0],
 [0, 1, 0, 0, 0, 0, 0, 0],
 [0, 0, 1, 0, 0, 0, 0, 0],
 [0, 0, 0, 1, 0, 0, 0, 0],
 [0, 0, 0, 0, 1, 0, 0, 0],
 [0, 0, 0, 0, 0, 1, 0, 0],
 [0, 0, 0, 0, 0, 0, 1, 0],
 [0, 0, 0, 0, 0, 0, 0, 1]]

double = [[1, 0, 0, 0, 0, 0, 0, 1],
 [0, 1, 0, 0, 0, 0, 1, 0],
 [0, 0, 1, 0, 0, 1, 0, 0],
 [0, 0, 0, 1, 1, 0, 0, 0],
 [0, 0, 0, 1, 1, 0, 0, 0],
 [0, 0, 1, 0, 0, 1, 0, 0],
 [0, 1, 0, 0, 0, 0, 1, 0],
 [1, 0, 0, 0, 0, 0, 0, 1]]

triple = [[1, 0, 1, 1, 1, 1, 0, 1],
 [0, 1, 0, 0, 0, 0, 1, 0],
 [1, 0, 1, 0, 0, 1, 0, 1],
 [1, 0, 0, 1, 1, 0, 0, 1],
 [1, 0, 0, 1, 1, 0, 0, 1],
 [1, 0, 1, 0, 0, 1, 0, 1],
 [0, 1, 0, 0, 0, 0, 1, 0],
 [1, 0, 1, 1, 1, 1, 0, 1]]

# Testing sending the control code for the button LED controller to see if there's SPI bus interference.
# I have MOSI tied to each 8x8 controller and to the LED controller. But the LED controller doesn't
# have a chip select. It just looks for a control sequence. I managed to convince myself on the logic
# analyzer that the control sequence wasn't possible when sending 8x8 commands, so there wasn't any
# danger of the button LED controller accidentally changing a button LED state.

# single = [[0, 0, 1, 0, 0, 1, 0, 1],
#  [0, 0, 1, 0, 0, 1, 0, 1],
#  [0, 0, 1, 0, 0, 1, 0, 1],
#  [0, 0, 1, 0, 0, 1, 0, 1],
#  [0, 0, 1, 0, 0, 1, 0, 1],
#  [0, 0, 1, 0, 0, 1, 0, 1],
#  [0, 0, 1, 0, 0, 1, 0, 1],
#  [0, 0, 1, 0, 0, 1, 0, 1]]

# double = [[0, 0, 1, 0, 0, 1, 0, 1],
#  [0, 0, 1, 0, 0, 1, 0, 1],
#  [0, 0, 1, 0, 0, 1, 0, 1],
#  [0, 0, 1, 0, 0, 1, 0, 1],
#  [0, 0, 1, 0, 0, 1, 0, 1],
#  [0, 0, 1, 0, 0, 1, 0, 1],
#  [0, 0, 1, 0, 0, 1, 0, 1],
#  [0, 0, 1, 0, 0, 1, 0, 1]]

# triple = [[0, 0, 1, 0, 0, 1, 0, 1],
#  [0, 0, 1, 0, 0, 1, 0, 1],
#  [0, 0, 1, 0, 0, 1, 0, 1],
#  [0, 0, 1, 0, 0, 1, 0, 1],
#  [0, 0, 1, 0, 0, 1, 0, 1],
#  [0, 0, 1, 0, 0, 1, 0, 1],
#  [0, 0, 1, 0, 0, 1, 0, 1],
#  [0, 0, 1, 0, 0, 1, 0, 1]]

score_displays = [ twenty, nineteen, eighteen, seventeen, sixteen, fifteen, bull ]

score_display_count = [ single, double, triple ]

score_count = [0, 0, 0, 0, 0, 0, 0]

# Used for blinking the game reset button
blink_timestamp_ns = 0
blink_brightness = 65535
blink_bright_down = True

# Helpful function for setting a score display.
def fill_matrix(score_display, matrix):
    for i_row, row in enumerate(score_display):
        for j_col, led_state in enumerate(row):
            matrix.pixel(j_col, i_row, led_state)

# Resets the game at power up and when user presses reset button.
def game_reset():
    # Turn off all the buttons
    for led_channel in score_button_led_channel:
        leds.set_channel(led_channel, 0)
    leds.show()

    # Turn off all LEDs
    for matrix in display_matrix:
        matrix.fill(False)
        matrix.show()

    # Pause
    time.sleep(0.5)

    # Turn on all the buttons
    for led_channel in score_button_led_channel:
        leds.set_channel(led_channel, 65535)
    leds.show()

    # Turn on all LEDs
    for matrix in display_matrix:
        matrix.fill(True)
        matrix.show()

    # Pause
    time.sleep(0.5)

    # Count up from Bull while gradually increasing score button brightness
    button_brightness = 0
    button_step = int(65535 / 28) # This is 7 score values x 4 brightness levels per score value
    for i_score, score in enumerate(reversed(score_displays)):
        for i, matrix in enumerate(display_matrix):
            fill_matrix(score, matrix)
            matrix.show()

        for j in range(0,4):
            button_brightness += button_step

            if button_brightness > (65535 - button_step): button_brightness = 65535 # Round up at the end
            for score_button in score_button_led_channel:
                leds.set_channel(score_button, button_brightness)
            leds.show()

            time.sleep(0.025)

    # Now set the scores to their correct values        
    time.sleep(0.3)
    for i, matrix in enumerate(display_matrix):
        leds.set_channel(score_button_led_channel[i], int(65535/3))
        leds.show()
        if i >= 0: # 20 is already displayed, so we can skip it.
            fill_matrix(score_displays[i], matrix)
            matrix.show()
            time.sleep(0.1)

    # Bring button lights back to full brightness
    time.sleep(0.3)
    for score_button in score_button_led_channel:
        leds.set_channel(score_button, 65535)
    leds.show()

    # These three blocks were animation experiments before I
    # settled on the final version.

    # This version just set displays back to 19, 18, 17, etc.
    # for i, matrix in enumerate(display_matrix):
    #     fill_matrix(score_displays[i], matrix)
    #     matrix.show()

    # This version counts down from 20
    # for i_score, score in enumerate(score_displays):
    #     for i, matrix in enumerate(display_matrix):
    #         if i >= i_score: 
    #             fill_matrix(score, matrix)
    #             matrix.show()
    #     time.sleep(0.4)

    # This version counts up from bull
    # for i_score, score in enumerate(reversed(score_displays)):
    #     for i, matrix in enumerate(reversed(display_matrix)):
    #         if i_score <= i: 
    #             fill_matrix(score, matrix)
    #             matrix.show()
    #     time.sleep(0.4)

    # Reset the score count.
    for i, score in enumerate(score_count):
        score_count[i] = 0

    # Reset the reset button blinker and game winning signal to
    # other board.
    blink_timestamp_ns = 0
    blink_brightness = 65535
    blink_bright_down = True
    serial_pins[TX].value = False

# Reset the game on power up.
game_reset()

# Test code for experimenting with display brightness.
# temp_bright = 10

# Main loop.
while True:
    # Scan the buttons
    for i, button in enumerate(score_buttons):
        # Update the button
        button.update()

        # Check for press
        # if button.value == True:
        # Check for button release
        if button.rose:
            # print("Button " + str(i) + " pressed")

            # Increment the score
            score_count[i] += 1
            if score_count[i] > 3: score_count[i] = 0

            # Check for whether to put button LED on or off
            if score_count[i] == 3:
                leds.set_channel(score_button_led_channel[i], 0)
                leds.show()
                # print("button LED off")
            else:
                leds.set_channel(score_button_led_channel[i], 65535)
                leds.show()
                # print("button LED on")

            # Mark the incremented score or reset to the default screen if count is back to zero.
            if score_count[i] == 0:
                for i_row, row in enumerate(score_displays[i]):
                    for j_col, led_state in enumerate(row):
                        display_matrix[i].pixel(j_col, i_row, led_state)
                display_matrix[i].show()
            else:
                for i_row, row in enumerate(score_display_count[score_count[i]-1]):
                    for j_col, led_state in enumerate(row):
                        display_matrix[i].pixel(j_col, i_row, led_state)
                display_matrix[i].show()

    # Alert other board if this is the end of game.
    if sum(score_count) == 21: serial_pins[TX].value = True
    else: serial_pins[TX].value = False

    # Blink the reset button if this in the end of game.
    # Note: the LED on the reset button is controlled by the board on the right, but we want to
    # use the same code on both boards. This code has no effect on the board on the left because
    # nothing is hooked to channel 7 on the LED controller.
    if sum(score_count) == 21 or serial_pins[RX].value:
        if time.monotonic_ns() > blink_timestamp_ns:
            # print("game over")

            if blink_bright_down:
                blink_brightness -= 1000
                if blink_brightness < 3000:
                    blink_brightness = 3000
                    blink_bright_down = False
            else:
                blink_brightness += 1000
                if blink_brightness > 65535:
                    blink_brightness = 65535
                    blink_bright_down = True

            leds.set_channel(score_button_led_channel[7], blink_brightness)
            leds.show()
            blink_timestamp_ns = time.monotonic_ns() + 15000000  # 15 ms
    # Game still going. This catches the case when someone clears a number and then un-clears it.
    elif blink_timestamp_ns != 0:
        blink_timestamp_ns = 0
        blink_brightness = 65535
        blink_bright_down = True
        leds.set_channel(score_button_led_channel[7], blink_brightness)
        leds.show()

    # Scan the reset button
    reset_button.update()
    if reset_button.rose:
        # print("reset pressed")
        game_reset()

    # test code for experimenting with brightness
    # temp_bright += 1
    # if temp_bright > 15: temp_bright = 0
    # print("bright " + str(temp_bright))
    # display_matrix[0].brightness(temp_bright)

# Test code to loop through all pixels on each 8x8 display
while False:
    # Turn on all LEDs
    for matrix in display_matrix:
        matrix.fill(True)
        matrix.show()

    # Turn on all the buttons
    for led_channel in score_button_led_channel:
        leds.set_channel(led_channel, 65535)
    leds.show()

    # Pause
    print("Heidi Ho there, neighbor")
    time.sleep(1.0)

    # Turn off all LEDs
    for matrix in display_matrix:
        matrix.fill(False)
        matrix.show()

    # Loop each display pixel by pixel to test addressing
    for i_row in range(0,8):
        for j_col in range (0,8):
            for matrix in display_matrix:
                matrix.pixel(j_col, i_row, 1)
                matrix.show()
            time.sleep(0.2)
            for matrix in display_matrix:
                matrix.pixel(j_col, i_row, 0)
                matrix.show()

# Test code to loop through all numbers and symbols on each 8x8 display
while False:

    time.sleep(0.1)

    matrix.fill(False)
    matrix.show()
    time.sleep(0.5)

    to_display = twenty

    for i, row in enumerate(to_display):
        for j, col in enumerate(row):
            display_matrix[0].pixel(j, i, col)
    display_matrix[0].show()
    time.sleep(2.0)

    to_display = nineteen

    for i, row in enumerate(to_display):
        for j, col in enumerate(row):
            display_matrix[0].pixel(j, i, col)
    display_matrix[0].show()
    time.sleep(2.0)

    to_display = eighteen

    for i, row in enumerate(to_display):
        for j, col in enumerate(row):
            display_matrix[0].pixel(j, i, col)
    display_matrix[0].show()
    time.sleep(2.0)

    to_display = seventeen

    for i, row in enumerate(to_display):
        for j, col in enumerate(row):
            display_matrix[0].pixel(j, i, col)
    display_matrix[0].show()
    time.sleep(2.0)

    to_display = sixteen

    for i, row in enumerate(to_display):
        for j, col in enumerate(row):
            display_matrix[0].pixel(j, i, col)
    display_matrix[0].show()
    time.sleep(2.0)

    to_display = fifteen

    for i, row in enumerate(to_display):
        for j, col in enumerate(row):
            display_matrix[0].pixel(j, i, col)
    display_matrix[0].show()
    time.sleep(2.0)

    to_display = bull

    for i, row in enumerate(to_display):
        for j, col in enumerate(row):
            display_matrix[0].pixel(j, i, col)
    display_matrix[0].show()
    time.sleep(2.0)

    to_display = single

    for i, row in enumerate(to_display):
        for j, col in enumerate(row):
            display_matrix[0].pixel(j, i, col)
    display_matrix[0].show()
    time.sleep(2.0)

    to_display = double

    for i, row in enumerate(to_display):
        for j, col in enumerate(row):
            display_matrix[0].pixel(j, i, col)
    display_matrix[0].show()
    time.sleep(2.0)

    to_display = triple

    for i, row in enumerate(to_display):
        for j, col in enumerate(row):
            display_matrix[0].pixel(j, i, col)
    display_matrix[0].show()
    time.sleep(2.0)
